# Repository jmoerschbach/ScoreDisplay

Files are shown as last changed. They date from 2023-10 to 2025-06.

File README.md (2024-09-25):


# Self-built ScoreDisplay
shows game time, score and halftime

# How to compile
use the Arduino IDE to compile the sketches. 
## Dependencies
Following libraries are needed to be installed via Arduino IDE Library Manager:
- FastLED
- RF24
- Smartbutton Library
## Shared Code
Since there is shared code and Arduino IDE does not support relative paths, there are two options:
- Windows (and Linux):
copy all the files except the (dummy) *.ino file inside Code/common into the respective sketch directories
- Linux only (but more elegant):
  - find out where the sketchbook location is (in Arduino IDE File -> Preferences, "Sketchbook location") and `cd` into the libraries folder of that directory
  - create a symlink from within the libraries folder to Code/common: `ln -s <path-where-you-cloned-into>/Code/common`

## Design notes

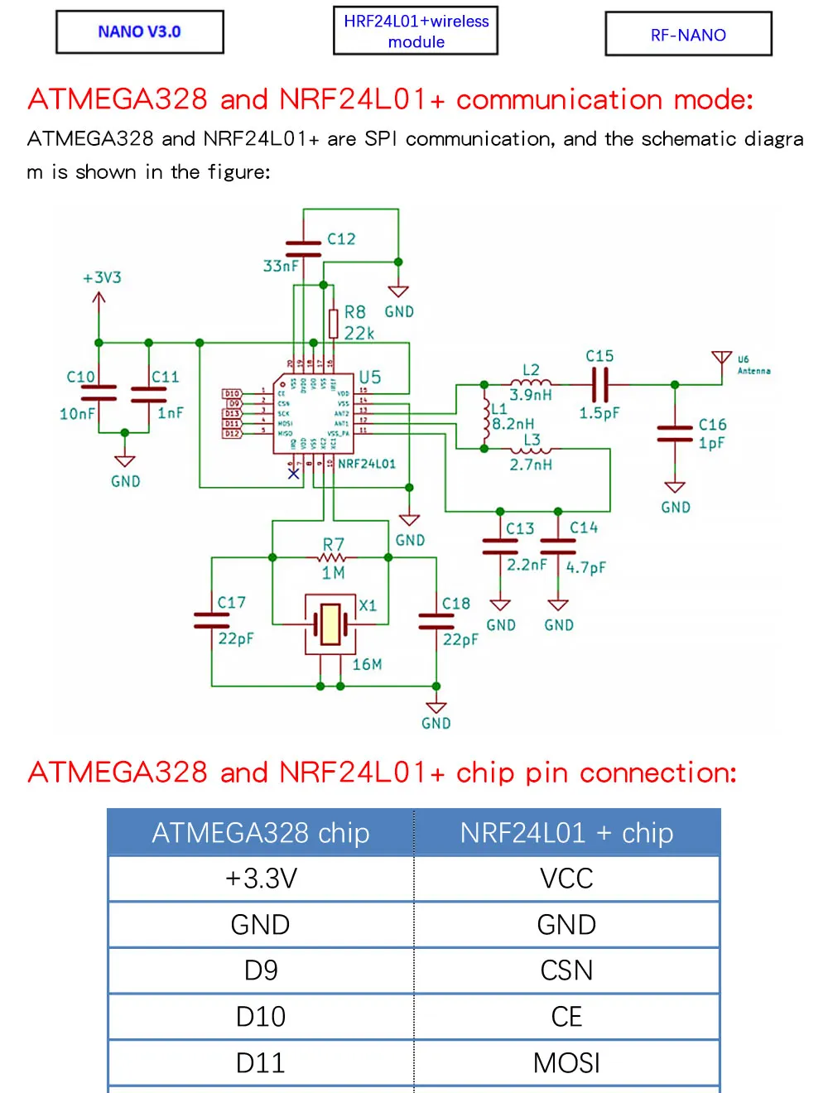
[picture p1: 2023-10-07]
rf-nano.webp

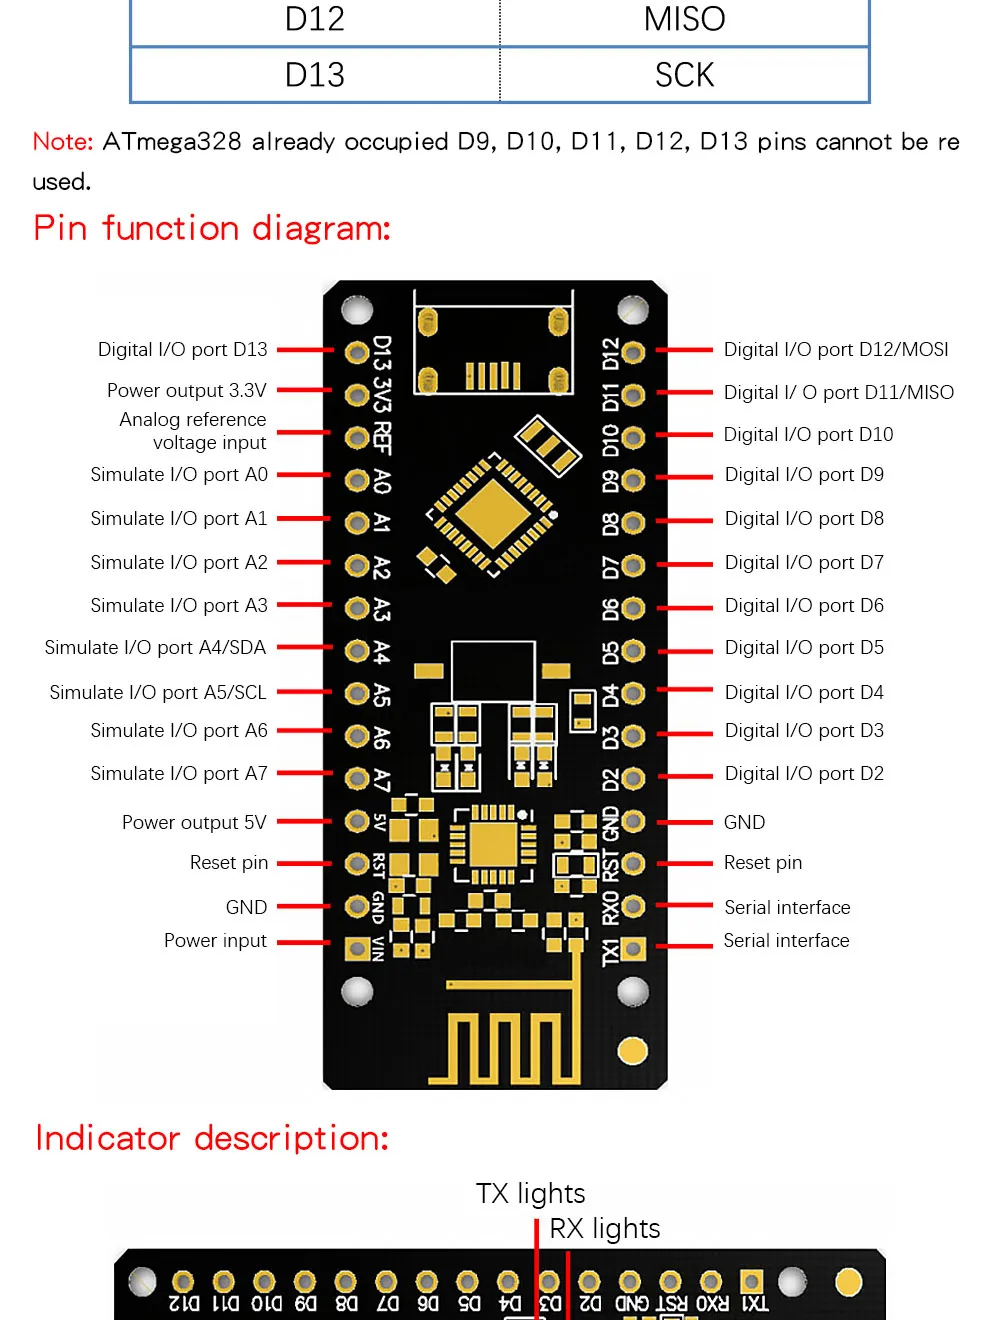
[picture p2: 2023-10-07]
rf-nano2.webp

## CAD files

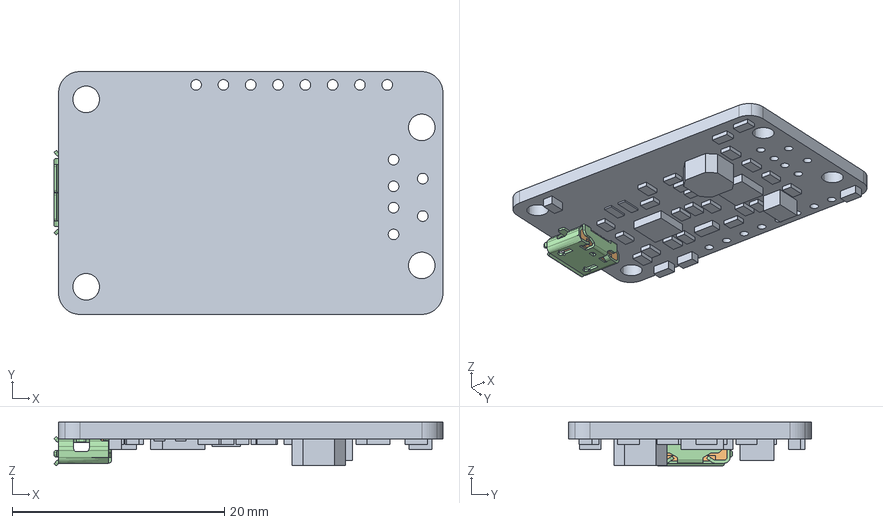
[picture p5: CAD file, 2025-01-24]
CAD/Components/powerboost 1000c.f3d v3.stp
36.6 x 22.9 x 4.12 mm

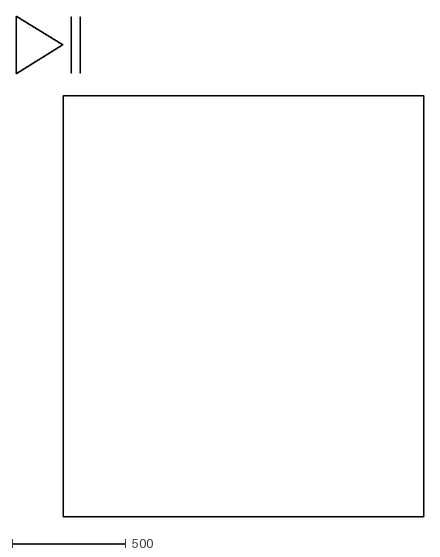
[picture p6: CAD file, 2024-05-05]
CAD/Icons/PlayPause.dxf
1794.9 x 2203.4

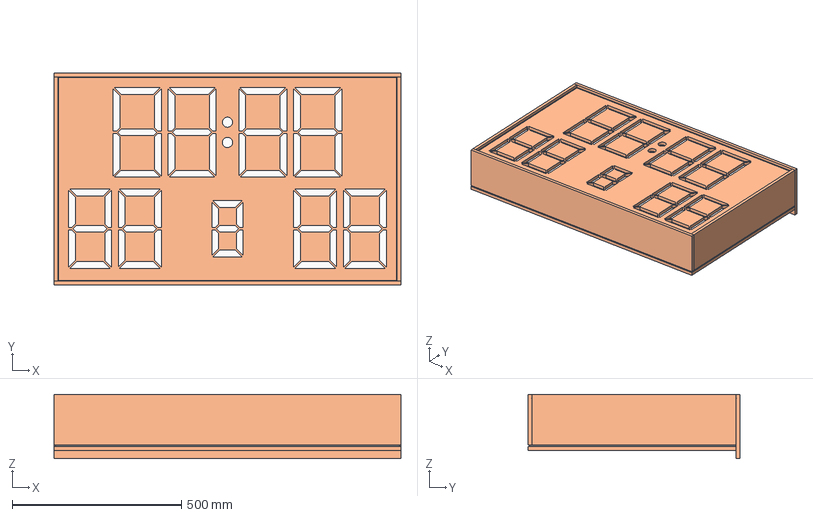
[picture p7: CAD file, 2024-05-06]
CAD/Scoreboard.stp
1026.0 x 626.0 x 190.0 mm
Aluminium_Grundplatte
Schablone
Querseite_Gehäuse x 2
Längsseite_Gehäuse
Längsseite_Gehäuse_1
Gummidichtung
Rückseite_Gehäuse

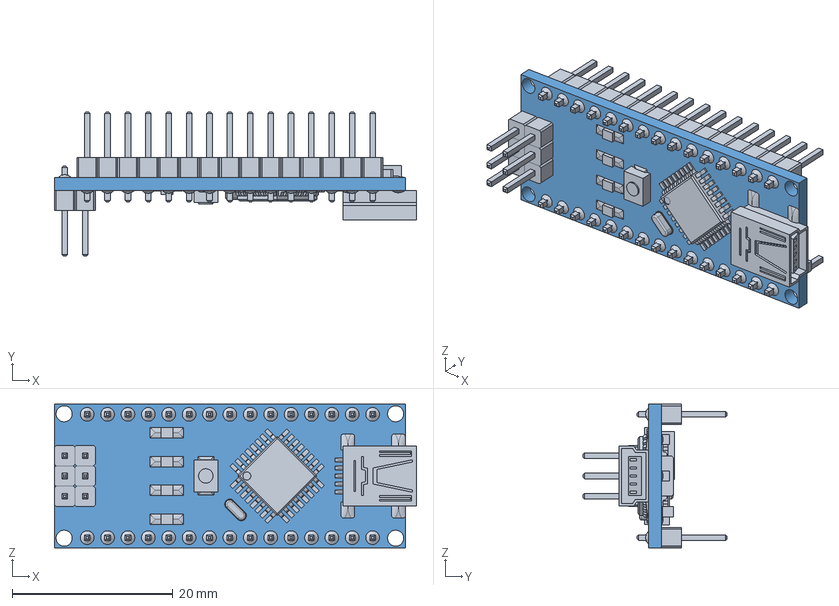
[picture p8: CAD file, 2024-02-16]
CAD/Components/NanoV3 v4.step
45.1 x 18.0 x 17.9 mm
switch
Led x 3
Led (1)
Pin x 21
chip1
USB
Crystal
Pin (1) x 15
Res x 5
cap x 2
Chip
respack x 2
diode
vreg

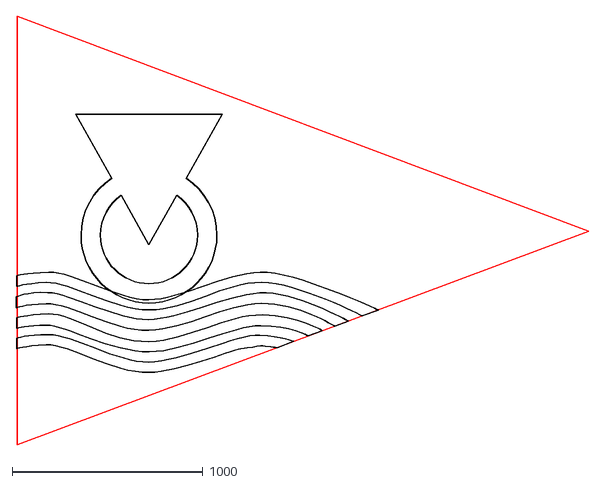
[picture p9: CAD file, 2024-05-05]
CAD/Icons/KCL-Logo_whiteContur.dxf
2998.7 x 2244.1

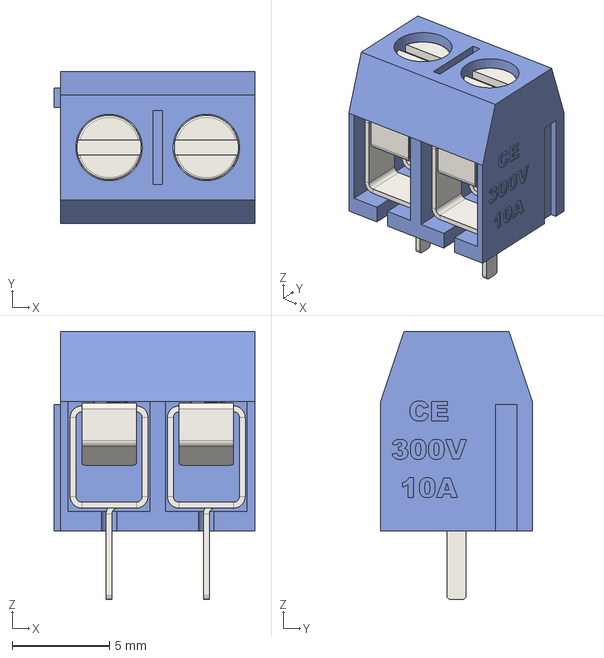
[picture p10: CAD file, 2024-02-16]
CAD/Components/dg-301-5_0-2P.step
10.3 x 7.80 x 13.8 mm

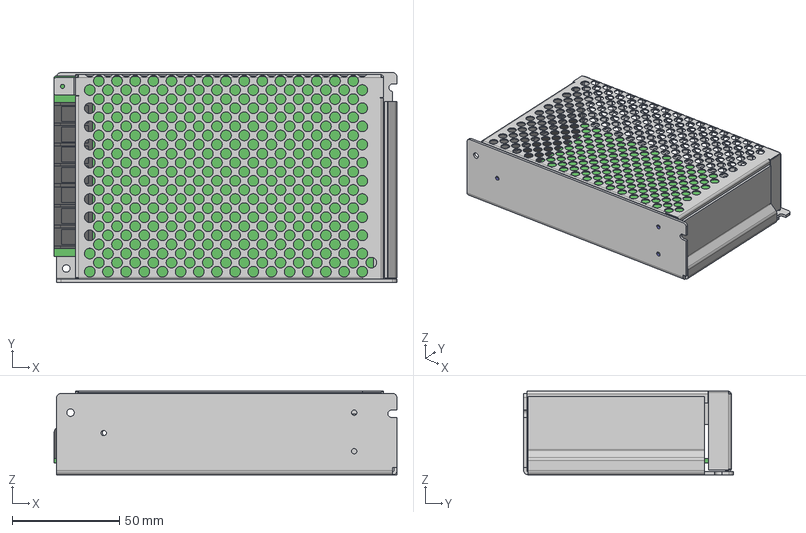
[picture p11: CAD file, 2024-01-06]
CAD/Components/MeanWell_RS-100.stp
160.2 x 98.0 x 39.0 mm
GRATE
PLATE
PCB
BLOCK

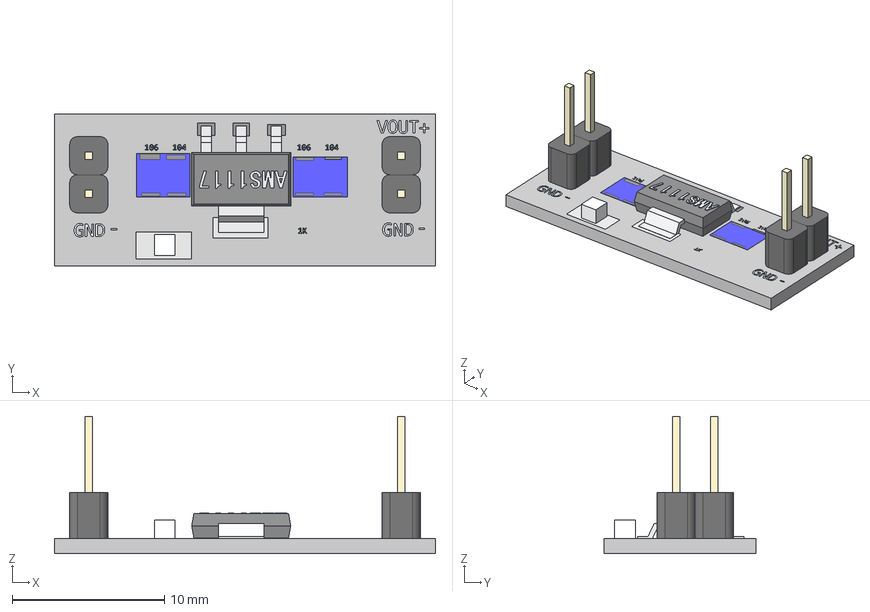
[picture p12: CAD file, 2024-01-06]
CAD/Components/DC-DC Stepper Aliexpress v4.step
25.0 x 10.0 x 9.00 mm
GND001
+(2)
VIN
GND
User_Library-AMS1117
Rectangle002
Rectangle003 x 2
Line
Line001
ShapeString008
Rectangle006
Rectangle007
Rectangle008
Rectangle009
ShapeString009
Rectangle010
Rectangle011
Rectangle012
Rectangle013
Rectangle014
Rectangle015
Rectangle016
Rectangle017
LED
Rectangle018
Rectangle019
Rectangle020
1K
DC-DC Step

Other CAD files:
CAD/Components/Aluminium_Grundplatte.ipt
CAD/Components/Druckknopf_Konsole_groß.ipt
CAD/Components/Druckknopf_Konsole_klein.ipt
CAD/Components/Druckknopf_Konsole_klein_MIR.ipt
CAD/Components/Grundplatte_Konsole.ipt
CAD/Components/Gummidichtung.ipt
CAD/Components/Längsseite_Gehäuse.ipt
CAD/Components/Längsseite_Konsole.ipt
CAD/Components/MDF_Anzeige.ipt
CAD/Components/Oberseite_Gehäuse.ipt
CAD/Components/Oberseite_Konsole.ipt
CAD/Components/Oberseite_Shotclock.ipt
CAD/Components/OldVersions/Druckknopf_Konsole_groß.0001.ipt
CAD/Components/OldVersions/Druckknopf_Konsole_klein.0002.ipt
CAD/Components/OldVersions/Längsseite_Gehäuse.0001.ipt
CAD/Components/OldVersions/Oberseite_Gehäuse.0002.ipt
CAD/Components/OldVersions/Oberseite_Konsole.0001.ipt
CAD/Components/OldVersions/Oberseite_Shotclock.0002.ipt
CAD/Components/OldVersions/Querseite_Gehäuse.0002.ipt
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

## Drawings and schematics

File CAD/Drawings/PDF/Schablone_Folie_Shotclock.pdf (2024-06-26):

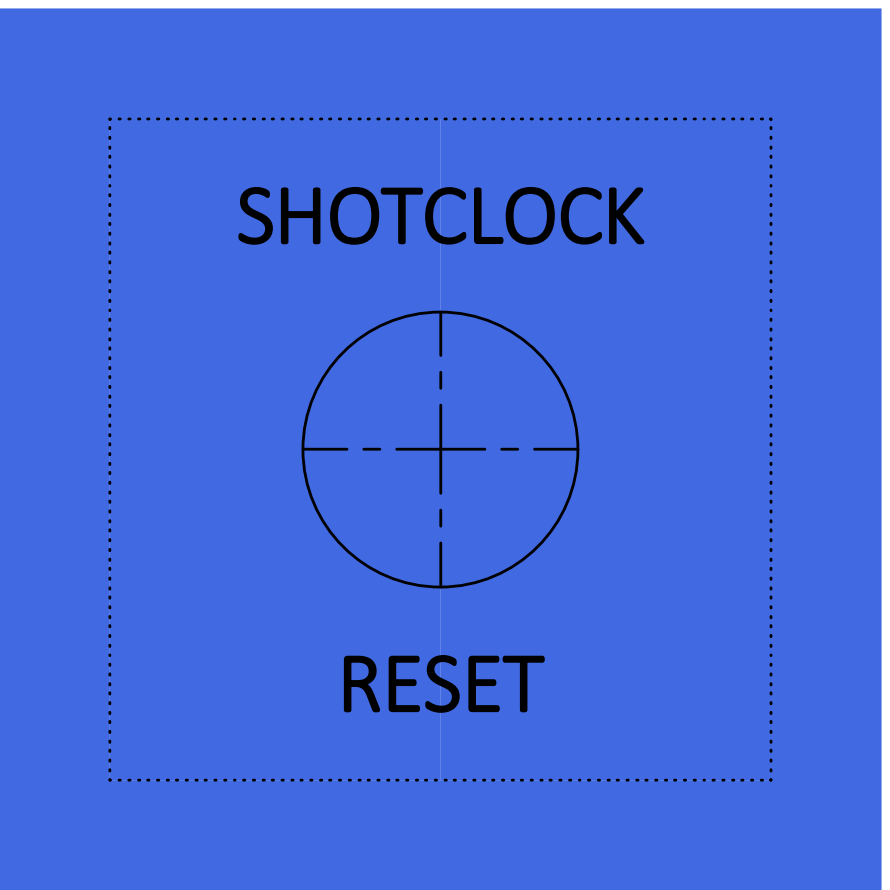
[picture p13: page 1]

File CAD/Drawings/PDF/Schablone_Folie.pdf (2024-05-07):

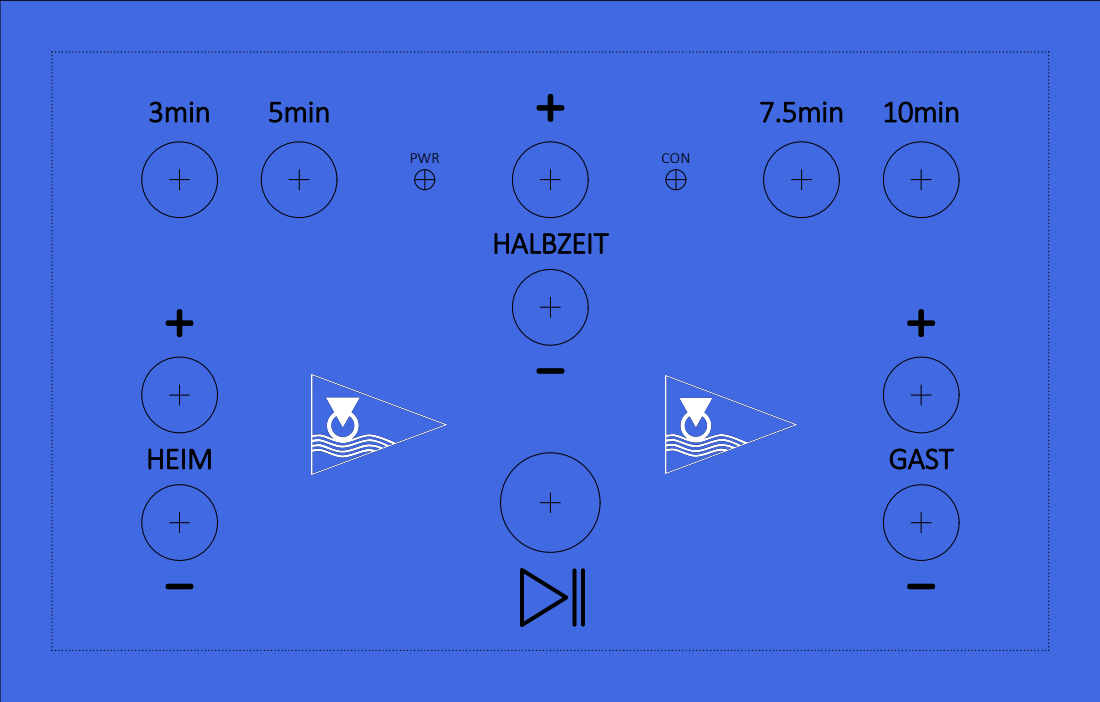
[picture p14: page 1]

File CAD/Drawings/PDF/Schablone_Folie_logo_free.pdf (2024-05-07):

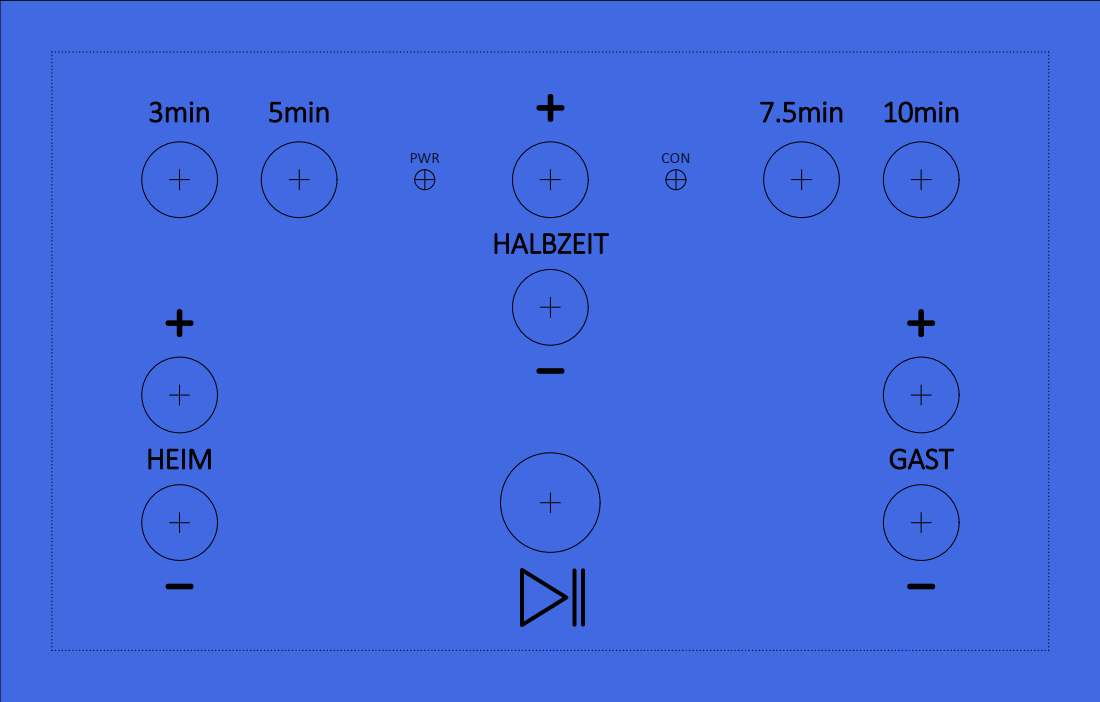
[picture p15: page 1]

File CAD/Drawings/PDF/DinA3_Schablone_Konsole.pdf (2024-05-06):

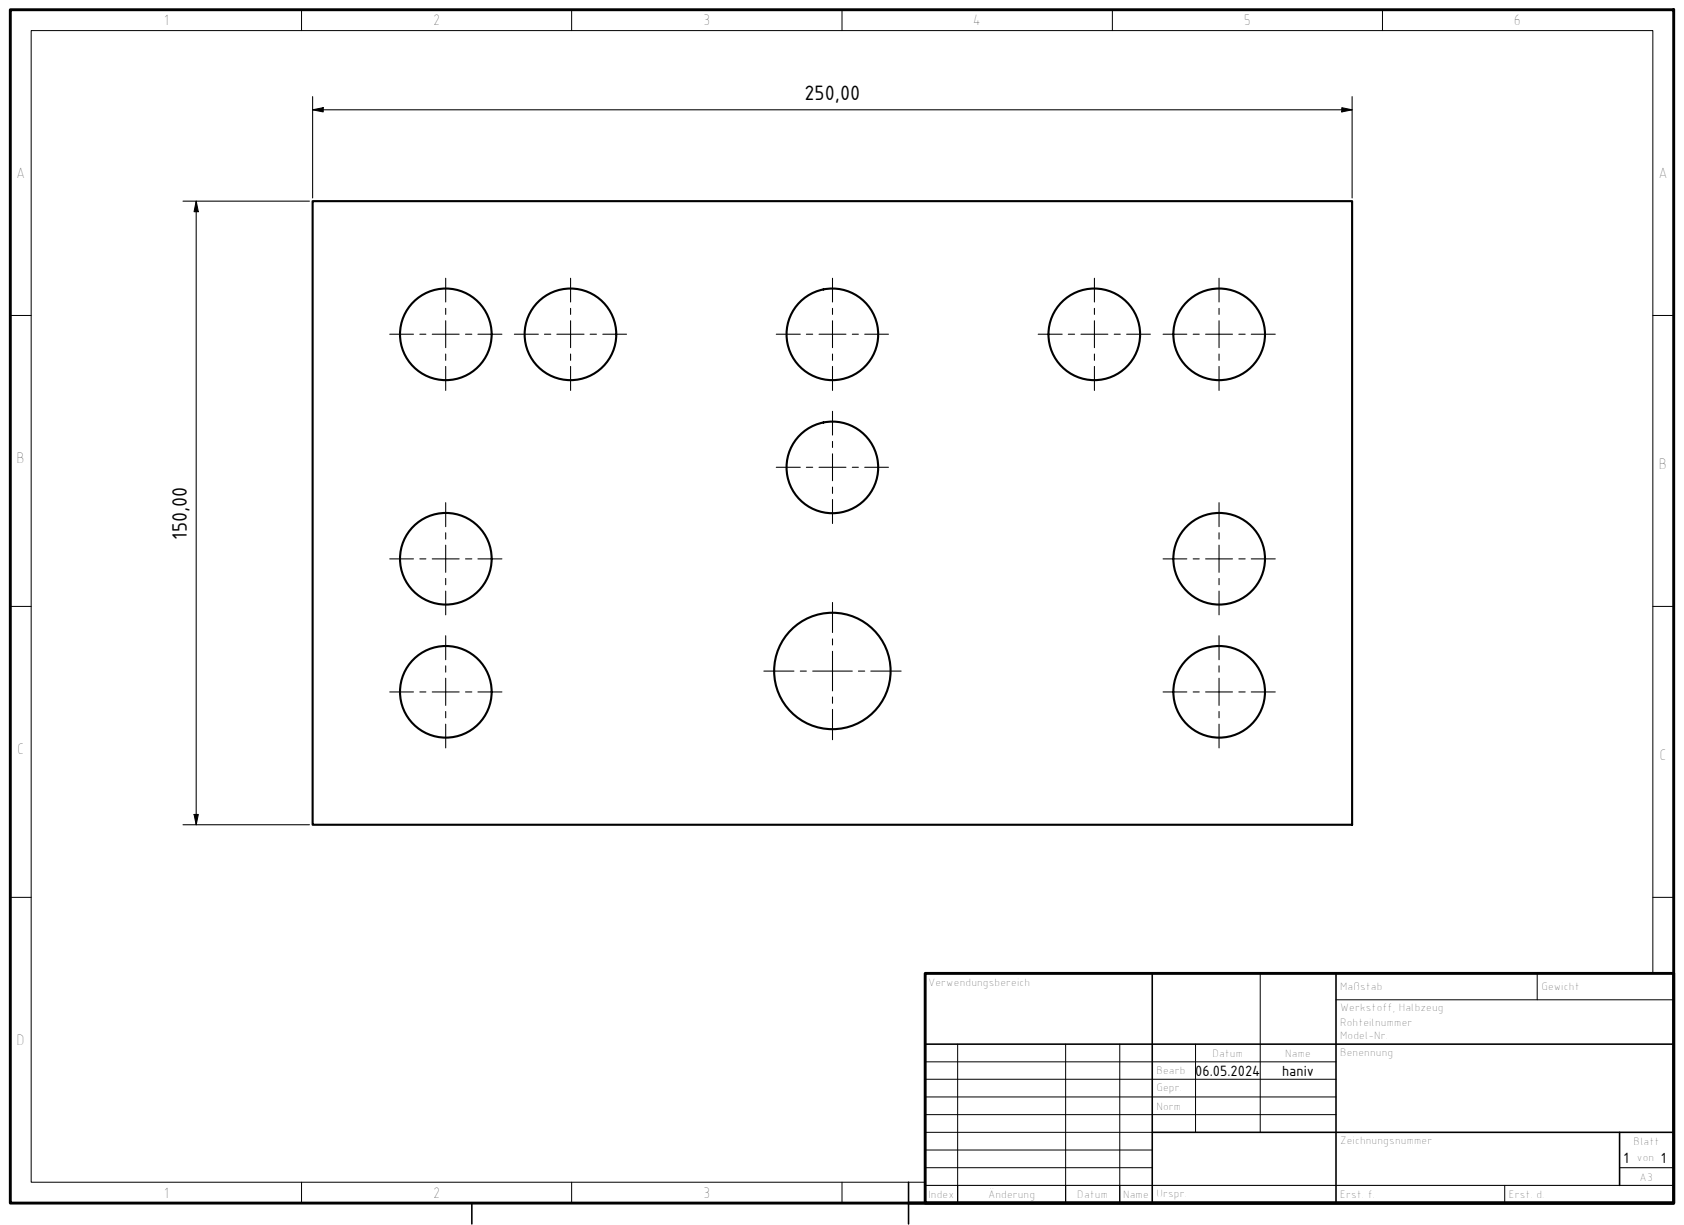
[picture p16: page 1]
Werkstoff, Halbzeug; Index; Änderung; Datum; Name; Urspr.; Erst. f.; Erst. d.

Datum | Name | Benennung

Bearb | 06.05.2024 | haniv
Gepr.
Norm

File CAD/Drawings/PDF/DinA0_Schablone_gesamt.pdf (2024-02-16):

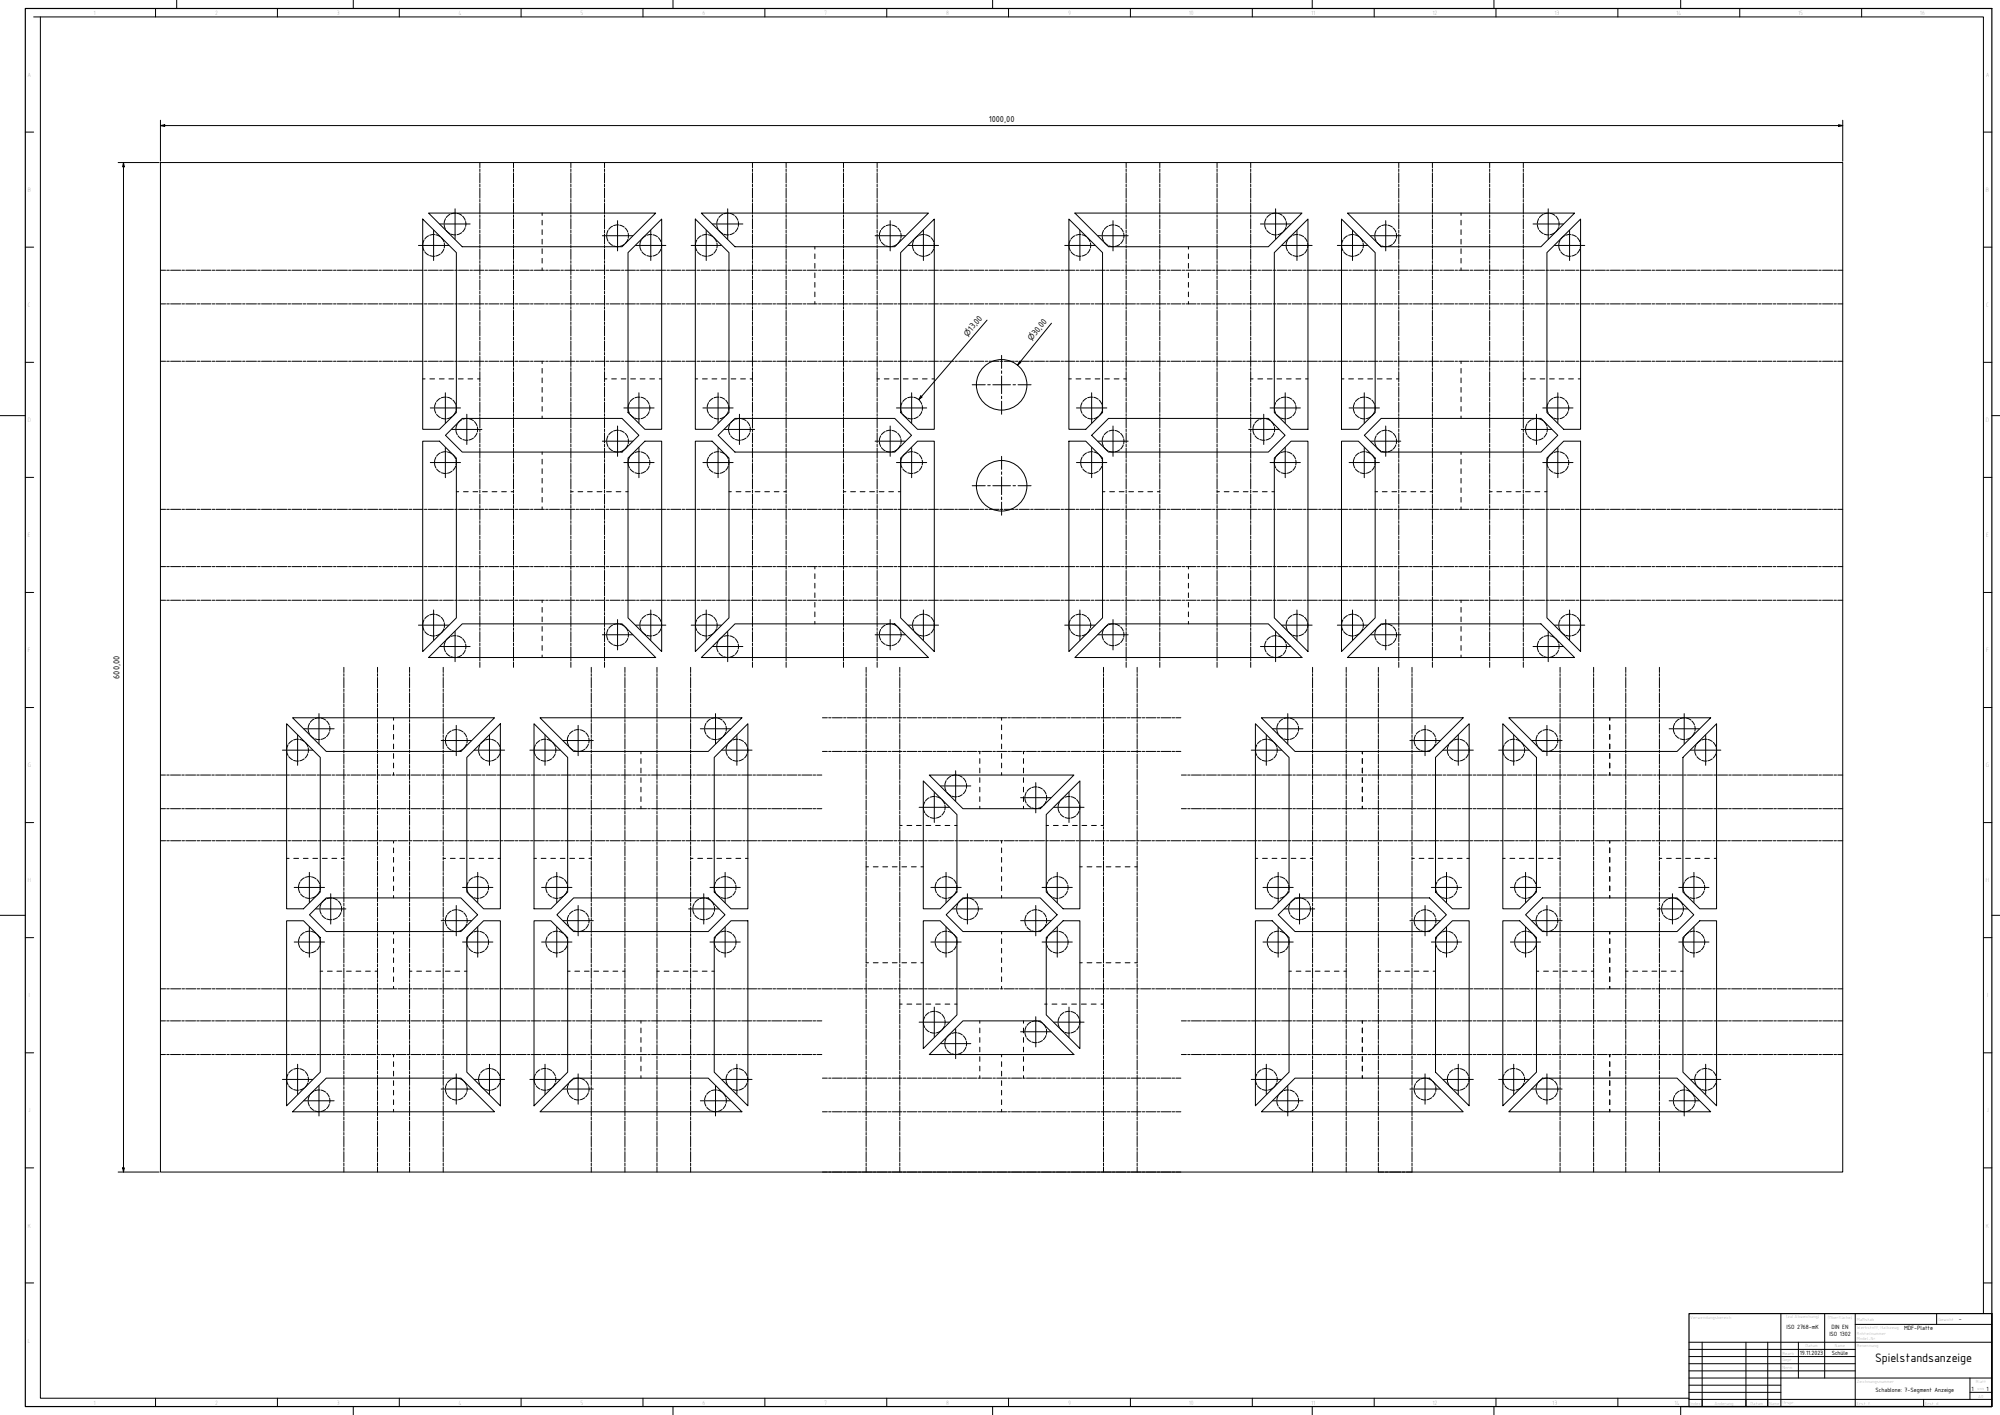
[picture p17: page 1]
Werkstoff, Halbzeug; Index; vnderung; Datum; Name; Urspr.; Erst. f.; Erst. d.; ISO 2768-mK; DIN EN ISO 1302

Datum | Name | Benennung Spielstandsanzeige

Bearb | 19.11.2023 | Sch¯le
Gepr.
Norm

Schablone: 7-Segment Anzeige

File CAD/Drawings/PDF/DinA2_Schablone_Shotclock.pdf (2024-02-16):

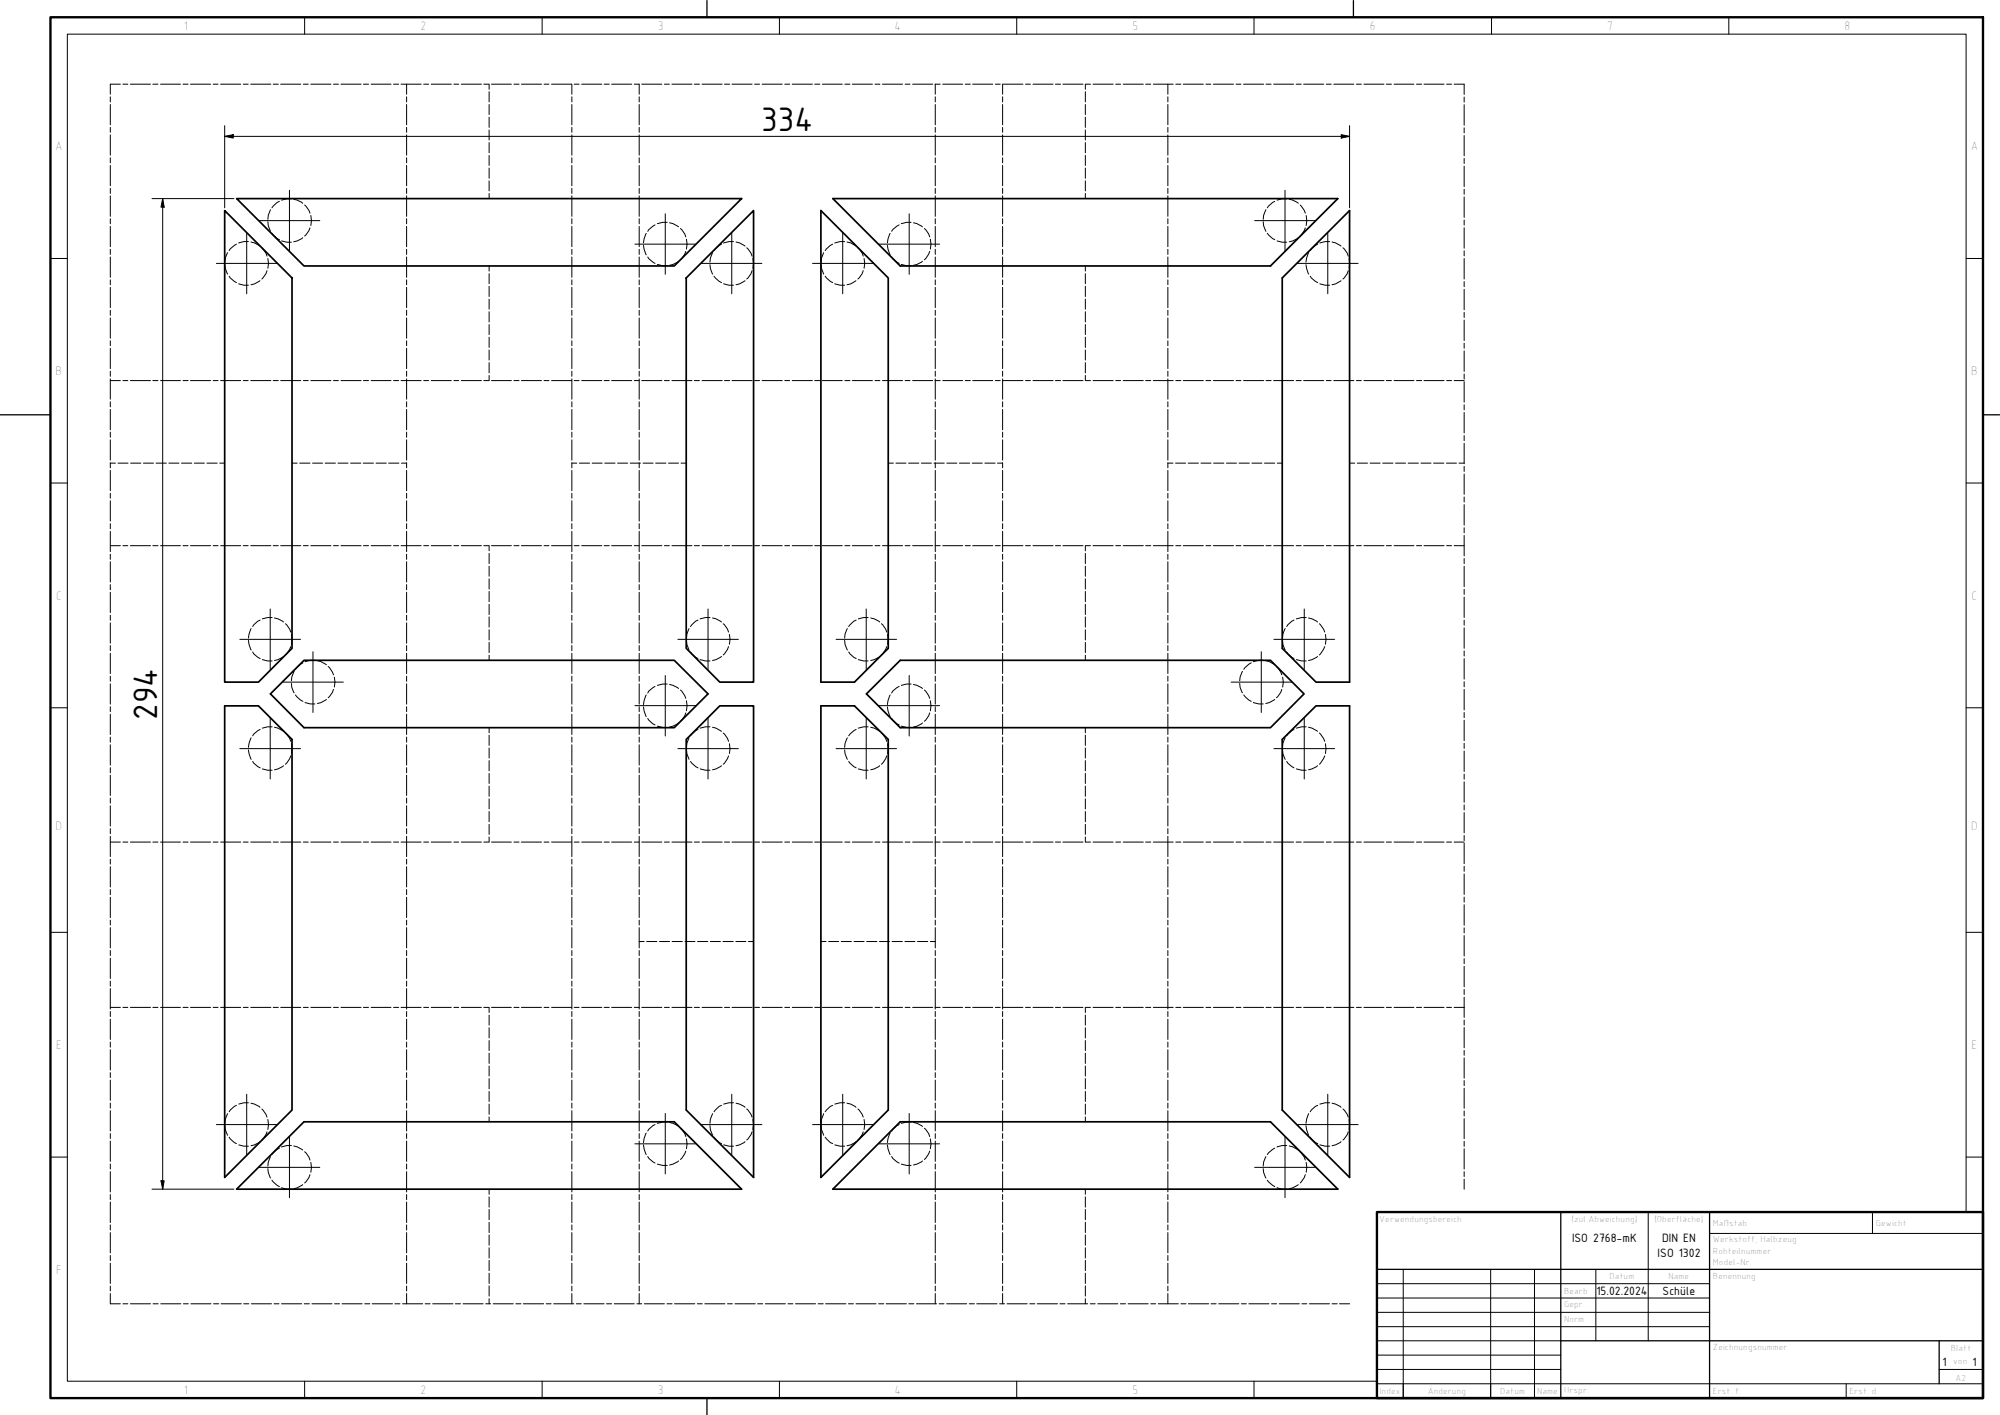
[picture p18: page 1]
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

Datum | Name | Benennung

Bearb | 15.02.2024 | Schüle
Gepr.
Norm

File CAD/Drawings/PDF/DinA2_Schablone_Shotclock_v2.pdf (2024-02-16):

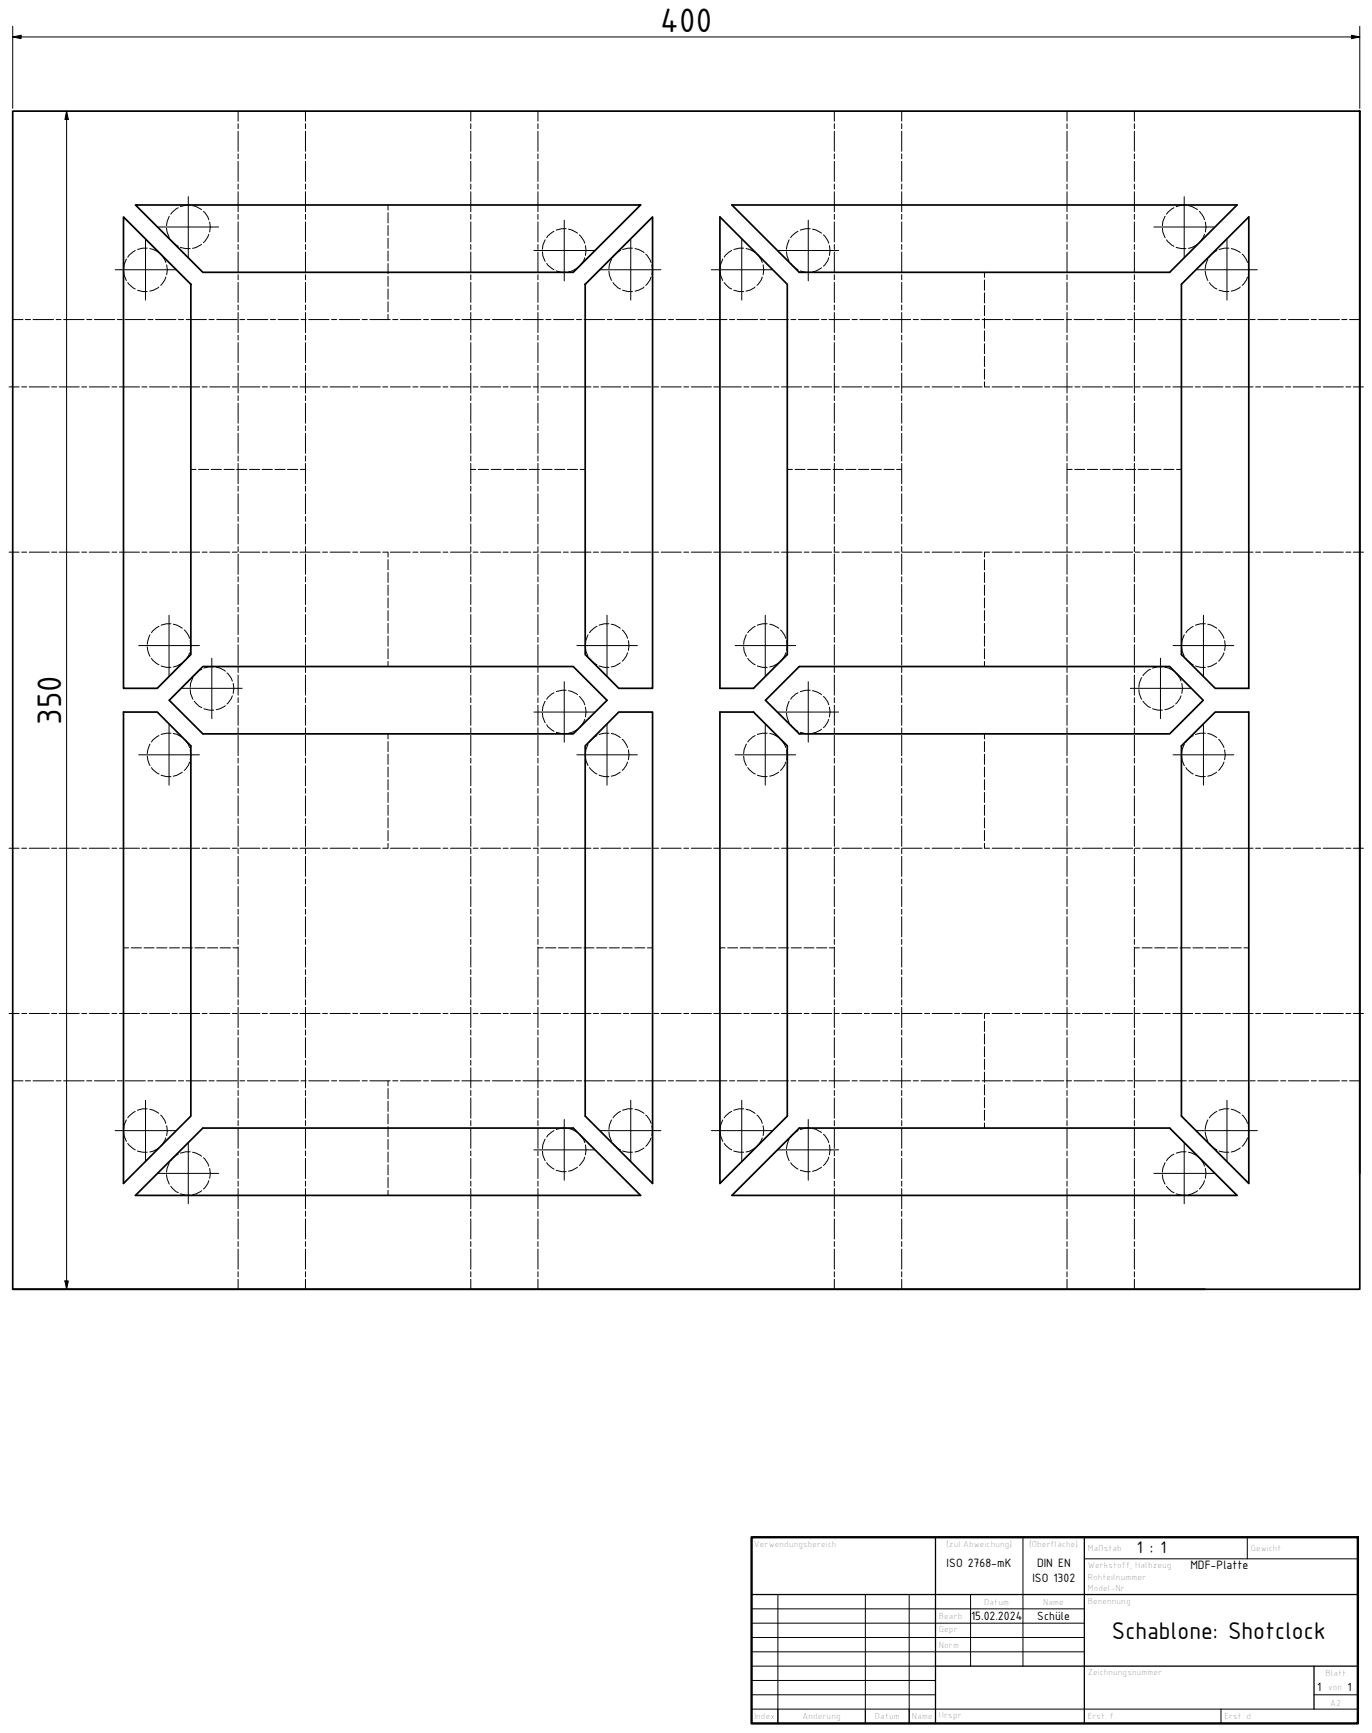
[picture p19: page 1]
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

Datum | Name | Benennung Schablone: Shotclock

Bearb | 15.02.2024 | Schüle
Gepr.
Norm

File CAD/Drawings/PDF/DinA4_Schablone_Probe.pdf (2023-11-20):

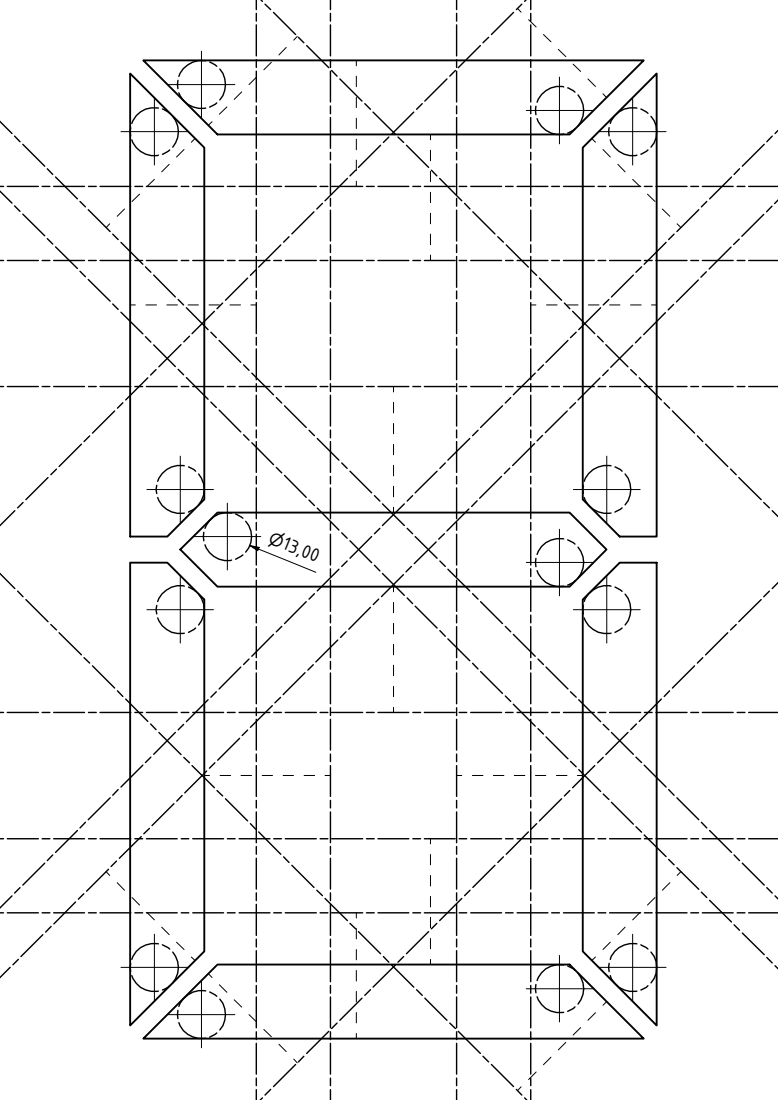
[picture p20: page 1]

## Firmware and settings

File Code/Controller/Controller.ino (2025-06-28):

#include <Arduino.h>
#include <RF24.h>
#include "ButtonConfiguration.h"
#include "Constants.h"
#include "DataPackages.h"
#include "Game.h"
#include "Utils.h"

constexpr int INDICATOR_LED_PIN = 1;
constexpr int BUZZER_PIN = A0;

RF24 radio(9, 10);                // CE, CSN
MainDisplayData mainDisplayData;  //datastructure sent to the main display
ShotclockData shotclockData;      //datastructure sent to the shotclock displays
Game game;


void onDataChangedCallback() {
  // mainDisplayData.brightness = 255;
  mainDisplayData.homeScore = game.getHomeScore();
  mainDisplayData.awayScore = game.getAwayScore();
  mainDisplayData.secondsToPlay = game.getTimeLeftToPlay();
  mainDisplayData.halftime = game.getHalfTime();
  mainDisplayData.showTime = game.isTimeVisible();
  mainDisplayData.beep = game.isBeep();

  mainDisplayData.timeColor = White;
  mainDisplayData.awayScoreColor = White;
  mainDisplayData.homeScoreColor = White;
  mainDisplayData.halftimeColor = Green;

  shotclockData.secondsToShot = game.getTimeLeftToShoot();
  shotclockData.enabled = game.isShotclockVisible();
  shotclockData.beep = game.isShotclockBeep();

  // if (game.isBeep()) {
  //   digitalWrite(BUZZER_PIN, HIGH);
  // } else {
  //   digitalWrite(BUZZER_PIN, LOW);
  // }

  send();
}


void send() {
  bool success = true;

  radio.openWritingPipe(ADDRESS_MAIN_DISPLAY);
  success &= radio.write(&mainDisplayData, sizeof(mainDisplayData));

  radio.openWritingPipe(ADDRESS_SHOTCLOCK_0);
  success &= radio.write(&shotclockData, sizeof(shotclockData));

  radio.openWritingPipe(ADDRESS_SHOTCLOCK_1);
  success &= radio.write(&shotclockData, sizeof(shotclockData));

  if (success) {
    digitalWrite(INDICATOR_LED_PIN, HIGH);
  } else {
    digitalWrite(INDICATOR_LED_PIN, LOW);
  }
}

void setup() {
  configureButtons();
  pinMode(INDICATOR_LED_PIN, OUTPUT);
  pinMode(BUZZER_PIN, OUTPUT);


  digitalWrite(INDICATOR_LED_PIN, LOW);
  digitalWrite(BUZZER_PIN, LOW);

  radio.begin();
  radio.setChannel(CHANNEL);
  radio.setPALevel(RF24_PA_MAX);
  radio.setDataRate(RF24_250KBPS);
  radio.stopListening();

  game.begin(onDataChangedCallback);
}

void loop() {
  SmartButton::service();
  game.loop();
}

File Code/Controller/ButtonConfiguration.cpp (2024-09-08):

#include "ButtonConfiguration.h"
#include "Game.h"
extern Game game;

GenericButtonConfiguration::GenericButtonConfiguration(
  int pin, ClickAction singleClickAction, ClickAction longPressRepeatAction = []() {}, ClickAction longPressAction = []() {}) {
  _pin = pin;
  _singleClickAction = singleClickAction;
  _longPressRepeatAction = longPressRepeatAction;
  _longPressAction = longPressAction;
}
void GenericButtonConfiguration::event(SmartButton *button, SmartButton::Event event, int clickCounter) {
  if (event == SmartButton::Event::CLICK) {
    _singleClickAction();
  } else if (event == SmartButton::Event::HOLD) {
    _longPressAction();
  } else if (event == SmartButton::Event::HOLD_REPEAT || event == SmartButton::Event::LONG_HOLD_REPEAT) {
    _longPressRepeatAction();
  }
}

bool GenericButtonConfiguration::isPressed(SmartButton *button) {
  return (digitalRead(_pin) == LOW) ? true : false;
}

//########## Button behaviour definition starts here ##########
GenericButtonConfiguration playPause = GenericButtonConfiguration(
  BTN_PLAY_PAUSE_PIN, []() {
    game.playPause();
  },
  []() {}, []() {
    game.toggleMode();
  });

GenericButtonConfiguration shotClock = GenericButtonConfiguration(
  BTN_SHOTCLOCK_RESET_PIN, []() {
    if (game.getTimeLeftToPlay() >= 60) {
      game.setTimeLeftToShoot(60);
    } else {
      game.setTimeLeftToShoot(game.getTimeLeftToPlay());
    }
  },
  []() {}, []() {
    game.enableDisableShotclock();
  });

GenericButtonConfiguration homeScoreIncrease = SingleClickRepeatButtonConfiguration(
  BTN_HOME_INCREASE_PIN, []() {
    game.increaseHomeScore();
  });

GenericButtonConfiguration homeScoreDecrease = SingleClickRepeatButtonConfiguration(
  BTN_HOME_DECREASE_PIN, []() {
    game.decreaseHomeScore();
  });

GenericButtonConfiguration awayScoreIncrease = SingleClickRepeatButtonConfiguration(
  BTN_AWAY_INCREASE_PIN, []() {
    game.increaseAwayScore();
  });

GenericButtonConfiguration awayScoreDecrease = SingleClickRepeatButtonConfiguration(
  BTN_AWAY_DECREASE_PIN, []() {
    game.decreaseAwayScore();
  });

GenericButtonConfiguration halfTimeIncrease = SingleClickRepeatButtonConfiguration(
  BTN_HALFTIME_INCREASE_PIN, []() {
    game.increaseHalfTime();
  });

GenericButtonConfiguration halfTimeDecrease = SingleClickRepeatButtonConfiguration(
  BTN_HALFTIME_DECREASE_PIN, []() {
    game.decreaseHalfTime();
  });


GenericButtonConfiguration time10Min = SingleClickButtonConfiguration(
  BTN_TIME_10_PIN, []() {
    game.setTimeLeftToPlay(10 * 60);
  });

GenericButtonConfiguration time7_5Min = SingleClickButtonConfiguration(
  BTN_TIME_7_5_PIN, []() {
    game.setTimeLeftToPlay(7 * 60 + 30);
  });

GenericButtonConfiguration time5Min = SingleClickButtonConfiguration(
  BTN_TIME_5_PIN, []() {
    game.setTimeLeftToPlay(5 * 60);
  });

GenericButtonConfiguration time3Min = SingleClickButtonConfiguration(
  BTN_TIME_3_PIN, []() {
    game.setTimeLeftToPlay(3 * 60);
  });

SmartButton btnPlayPause(&playPause);
SmartButton btnShotclockReset(&shotClock);
SmartButton btnHomeIncrease(&homeScoreIncrease);
SmartButton btnHomeDecrease(&homeScoreDecrease);
SmartButton btnAwayIncrease(&awayScoreIncrease);
SmartButton btnAwayDecrease(&awayScoreDecrease);
SmartButton btnHalftimeIncease(&halfTimeIncrease);
SmartButton btnHalftimeDecrease(&halfTimeDecrease);
SmartButton btnTime10(&time10Min);
SmartButton btnTime7_5(&time7_5Min);
SmartButton btnTime5(&time5Min);
SmartButton btnTime3(&time3Min);

void configureButtons() {
  pinMode(BTN_SHOTCLOCK_RESET_PIN, INPUT_PULLUP);
  pinMode(BTN_PLAY_PAUSE_PIN, INPUT_PULLUP);
  pinMode(BTN_HOME_INCREASE_PIN, INPUT_PULLUP);
  pinMode(BTN_HOME_DECREASE_PIN, INPUT_PULLUP);
  pinMode(BTN_AWAY_INCREASE_PIN, INPUT_PULLUP);
  pinMode(BTN_AWAY_DECREASE_PIN, INPUT_PULLUP);
  pinMode(BTN_HALFTIME_INCREASE_PIN, INPUT_PULLUP);
  pinMode(BTN_HALFTIME_DECREASE_PIN, INPUT_PULLUP);

  pinMode(BTN_TIME_10_PIN, INPUT_PULLUP);
  pinMode(BTN_TIME_7_5_PIN, INPUT_PULLUP);
  pinMode(BTN_TIME_5_PIN, INPUT_PULLUP);
  pinMode(BTN_TIME_3_PIN, INPUT_PULLUP);

  btnPlayPause.begin();
  btnShotclockReset.begin();
  btnHomeIncrease.begin();
  btnHomeDecrease.begin();
  btnAwayIncrease.begin();
  btnAwayDecrease.begin();
  btnHalftimeIncease.begin();
  btnHalftimeDecrease.begin();
  btnTime10.begin();
  btnTime7_5.begin();
  btnTime5.begin();
  btnTime3.begin();
}

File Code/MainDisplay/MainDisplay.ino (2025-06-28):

#include <RF24.h>
#include "Constants.h"
#include "SevenSegmentVisualization.h"
#include "DataPackages.h"

constexpr int HORN_PIN = 0;

RF24 radio(9, 10);  // CE, CSN
SevenSegmentVisualization visualization;


MainDisplayData data;
void setup() {
  pinMode(HORN_PIN, OUTPUT);
  digitalWrite(HORN_PIN, LOW); //turn off horn
  radio.begin();
  radio.setChannel(CHANNEL);
  radio.openReadingPipe(0, ADDRESS_MAIN_DISPLAY);
  radio.setPALevel(RF24_PA_MAX);
  radio.setDataRate(RF24_250KBPS);
  radio.startListening();


  visualization.begin();
  visualization.visualize(data);
}


void loop() {
  if (radio.available()) {
    radio.read(&data, sizeof(data));
    visualization.visualize(data);

    if (data.beep) {
      digitalWrite(HORN_PIN, HIGH);
    } else {
      digitalWrite(HORN_PIN, LOW);
    }
  }
}

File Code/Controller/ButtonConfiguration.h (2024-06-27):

#ifndef _BUTTONCONFIGURATION_h
#define _BUTTONCONFIGURATION_h
#include <SmartButton.h>

constexpr int BTN_HOME_INCREASE_PIN = 3;
constexpr int BTN_HOME_DECREASE_PIN = 4;
constexpr int BTN_AWAY_INCREASE_PIN = 5;
constexpr int BTN_AWAY_DECREASE_PIN = 6;
constexpr int BTN_HALFTIME_INCREASE_PIN = 7;
constexpr int BTN_HALFTIME_DECREASE_PIN = 8;

constexpr int BTN_TIME_3_PIN = A3;
constexpr int BTN_TIME_5_PIN = A2;
constexpr int BTN_TIME_7_5_PIN = A5;
constexpr int BTN_TIME_10_PIN = A4;

constexpr int BTN_SHOTCLOCK_RESET_PIN = A1;
constexpr int BTN_PLAY_PAUSE_PIN = 2;

using namespace smartbutton;
using ClickAction = void (*)(void);


/**
* This is a small wrapper class to ease the usage of the SmartButton-Api.
* It offers the possibility to define a button's behavior via lambdas for single click, long press and long press repeat events.
*/
class GenericButtonConfiguration : public SmartButtonInterface {

public:
  GenericButtonConfiguration(
    int pin, ClickAction singleClickAction, ClickAction longPressRepeatAction = []() {}, ClickAction longPressAction = []() {});
  virtual void event(SmartButton *button, SmartButton::Event event, int clickCounter);

  virtual bool isPressed(SmartButton *button);

private:
  int _pin;
  ClickAction _singleClickAction;
  ClickAction _longPressRepeatAction;
  ClickAction _longPressAction;
};

/**
* This is a SingleClickButton with no long press and long press repeat support.
*/
class SingleClickButtonConfiguration : public GenericButtonConfiguration {
public:
  SingleClickButtonConfiguration(int pin, ClickAction singleClickAction)
    : GenericButtonConfiguration(pin, singleClickAction, []() {}, []() {}) {}
};

/**
* This is a SingleClickButton which triggers the same action when long pressed.
*/
class SingleClickRepeatButtonConfiguration : public GenericButtonConfiguration {
public:
  SingleClickRepeatButtonConfiguration(int pin, ClickAction singleClickAction)
    : GenericButtonConfiguration(pin, singleClickAction, singleClickAction, []() {}) {}
};

void configureButtons();

#endif

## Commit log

2023-11-18 make Game feature complete
    use Timer to generate overflow with 1Hz
    implement play/pause correctly
    [MainDisplay.ino]
2024-01-06 add pcb including step files
    [DC-DC Stepper Aliexpress v4.step, MeanWell_RS-100.stp, NanoV3 v4.step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]
2024-01-12 generalize PCB so it can be used for all components. add step model as well
2024-02-16 Template for ShotclockDisplay (#1)
    * Template for ShotclockDisplay
    * Shotclock_v2 und Anpassung CAD Datenstruktur
    * Delete DinA2_Schablone_Shotclock.pdf
    [Aluminium_Grundplatte.ipt, DC-DC Stepper Aliexpress v4.step, MDF_Anzeige.ipt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]
2024-03-05 small bugfix + add color parameter to sevensegmentdigit
    [MainDisplay.ino, SevenSegmentVisualization.h]
2024-05-05 set correct pin for shotclock data out
    [SevenSegmentVisualization.h]
2024-05-05 add icons for control panel
    [KCL-Logo_whiteContur.dxf, PlayPause.dxf]
2024-05-06 fix frequency and addressing
    [Controller.ino]
2024-05-06 Schablone / Folien
    [Console.0002.iam, Console.iam, Druckknopf_Konsole_groß.0001.ipt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]
2024-05-07 Folien Update
    [Schablone_Folie.0001.idw, Schablone_Folie.idw]
2024-05-24 change freqenzy to higher value to avoid as much as possible usual 2.4Ghz devices like Wifi, Bluetooth, ...
    [Shotclock.ino]
2024-06-01 add basic support for buttons
2024-06-02 refactor Button wrapper and enable Score and Halftime buttons
2024-06-02 enable time preset buttons
2024-06-09 add buzzer support for shotclocks
    [Shotclock.ino]
2024-06-10 Folie Shotclock
    [Schablone_Folie_Shotclock.0001.idw, Schablone_Folie_Shotclock.idw]
2024-06-21 extract ButtonConfiguration into .h and .cpp
2024-06-21 use compare match of timer1 properly to have 2 separate intervals. Use 1s interval to enable playPause button
2024-06-21 add shotclock button
2024-06-26 small refactoring: move button configuration
2024-06-26 Update: Folie Shotclock 100x100
    [Schablone_Folie_Shotclock.0001.idw, Schablone_Folie_Shotclock.0002.idw, Schablone_Folie_Shotclock.idw]
2024-06-30 get rid of platform specific headers where possible. Extract constants and add documentation. Prepare for second system (with higher LED density)
2024-07-01 rename macro & prepare for higher led density
2024-09-08 reset shotclock to gametime when gametime < 60s
    [ButtonConfiguration.cpp]
2025-01-23 battery testing
2025-01-24 v0.2 schematic
    [powerboost 1000c.f3d v3.stp]
2025-02-14 increase diameter of powerboost footprint, mirror legend
2025-03-08 add library
    [5cdc65eb-5de0-4550-aa7f-840cc5b1dfe4.step, a93bb066-8cc0-4dfb-86fc-418c790c5c99.step, c871747d-19d1-4987-9f78-f71fdc88326d.step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]
2025-04-13 add definition of BatteryMonitor
2025-05-29 complete battery monitor impl
    Add timer for repeating the measurement (currently 1/min)
2025-06-01 some more battery soc things
2025-07-12 follow AI proposal to potential fix timer issue
    lets see if this still works and fixes anything
2025-07-12 Removed some librepcb libs - why?
    [5cdc65eb-5de0-4550-aa7f-840cc5b1dfe4.step, a93bb066-8cc0-4dfb-86fc-418c790c5c99.step, c871747d-19d1-4987-9f78-f71fdc88326d.step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]
